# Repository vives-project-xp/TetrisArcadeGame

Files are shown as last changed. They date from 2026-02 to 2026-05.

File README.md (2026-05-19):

# TETRIS ARCADE GAME






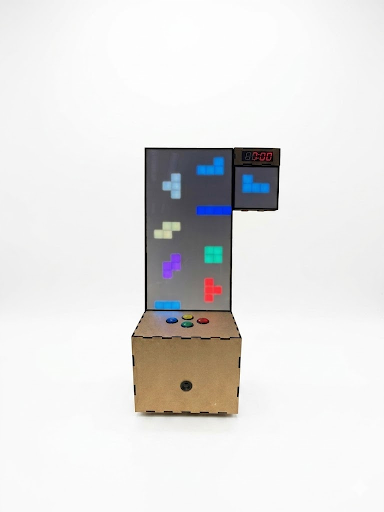
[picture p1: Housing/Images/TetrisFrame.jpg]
Tetris Frame


## Table of Contents
- [Team](#team)
- [Project Overview](#project-overview)
- [Features](#features)
- [Documentation](#documentation)
- [Posters](#posters)
- [Project Structure](#project-structure)

## Team
- [Danae Zutterman](https://github.com/Danaezutterman)
- [Lars Ysebaert](https://github.com/LarsYse)
- [Finn Van Peteghem](https://github.com/finn6698)
- [Timo Plets](https://github.com/TimoPlts)
- [Ondřej Kozel](https://github.com/ondrejkozel)

## Project Overview
This project focuses on the design and realization of a physical Tetris arcade game inside a custom-built housing. The game is displayed in real time on an LED game board and includes a scoreboard and a next-block display. A Raspberry Pi acts as the main controller, handling the physical button inputs while driving the LED matrix and speaker output.

The system is designed as a complete arcade experience rather than only a software project. In addition to the game logic, this repository also contains documentation for the hardware, housing, posters, and Raspberry Pi autostart setup.

## Documentation
- [Documentation overview](./Documentation/README.md) for the full documentation index
- [Architecture](./Documentation/Architecture/README.md) for the electrical and LED diagrams
- [Autostart](./Documentation/Autostart/Autostartscript.md) for the Raspberry Pi `systemd` service setup
- [Housing](./Housing/README.md) for the housing and laser-cutting related files

## Posters
<div style="display: flex; gap: 10px;">
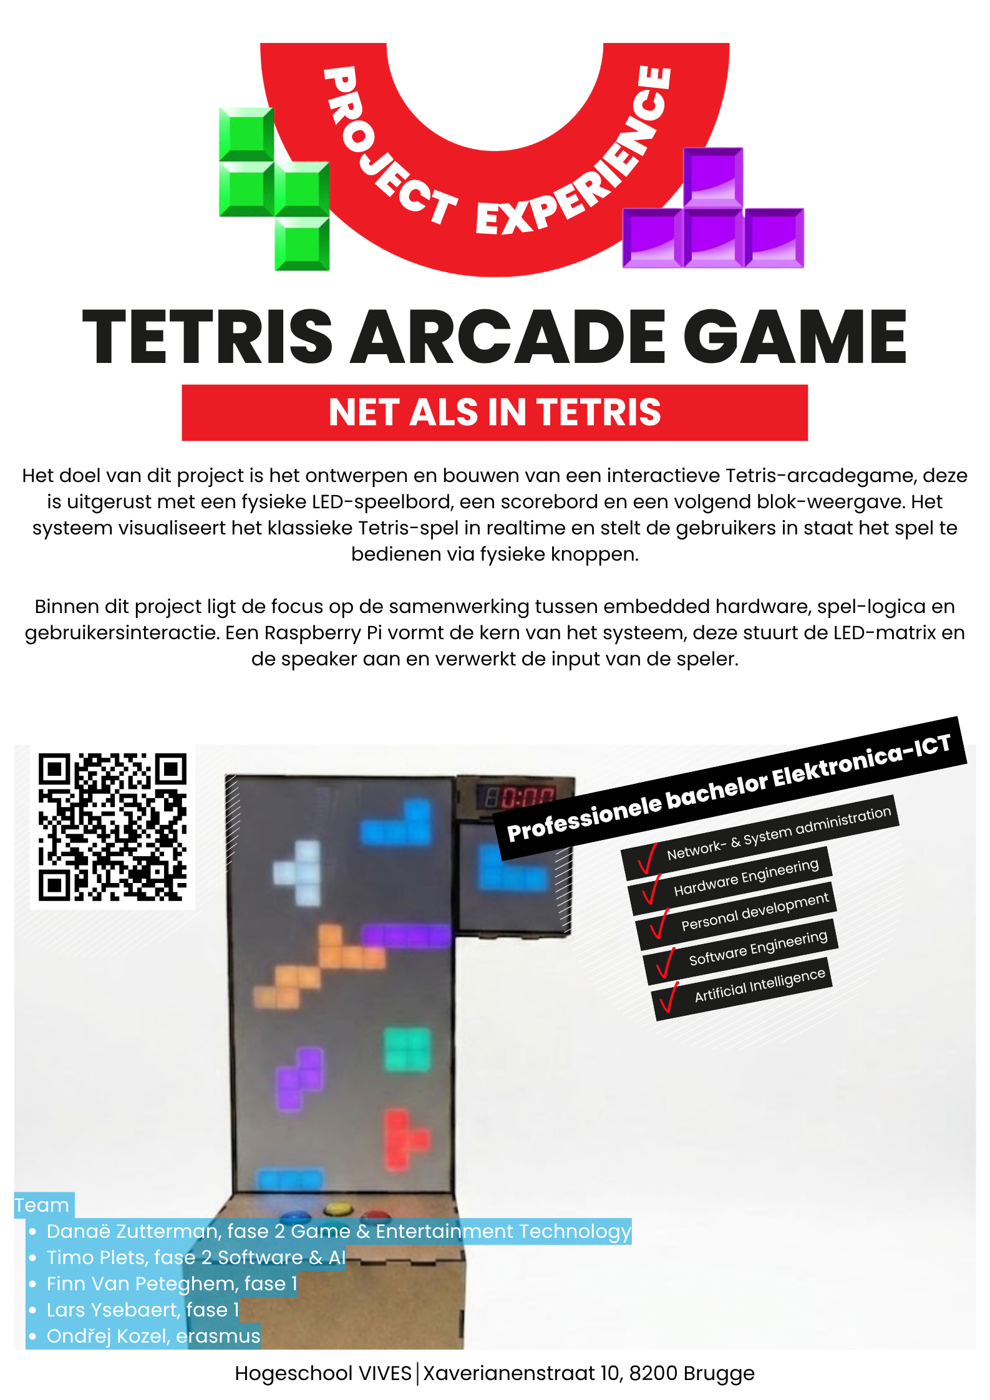
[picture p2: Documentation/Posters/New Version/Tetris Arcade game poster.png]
Tetris Arcade poster
   
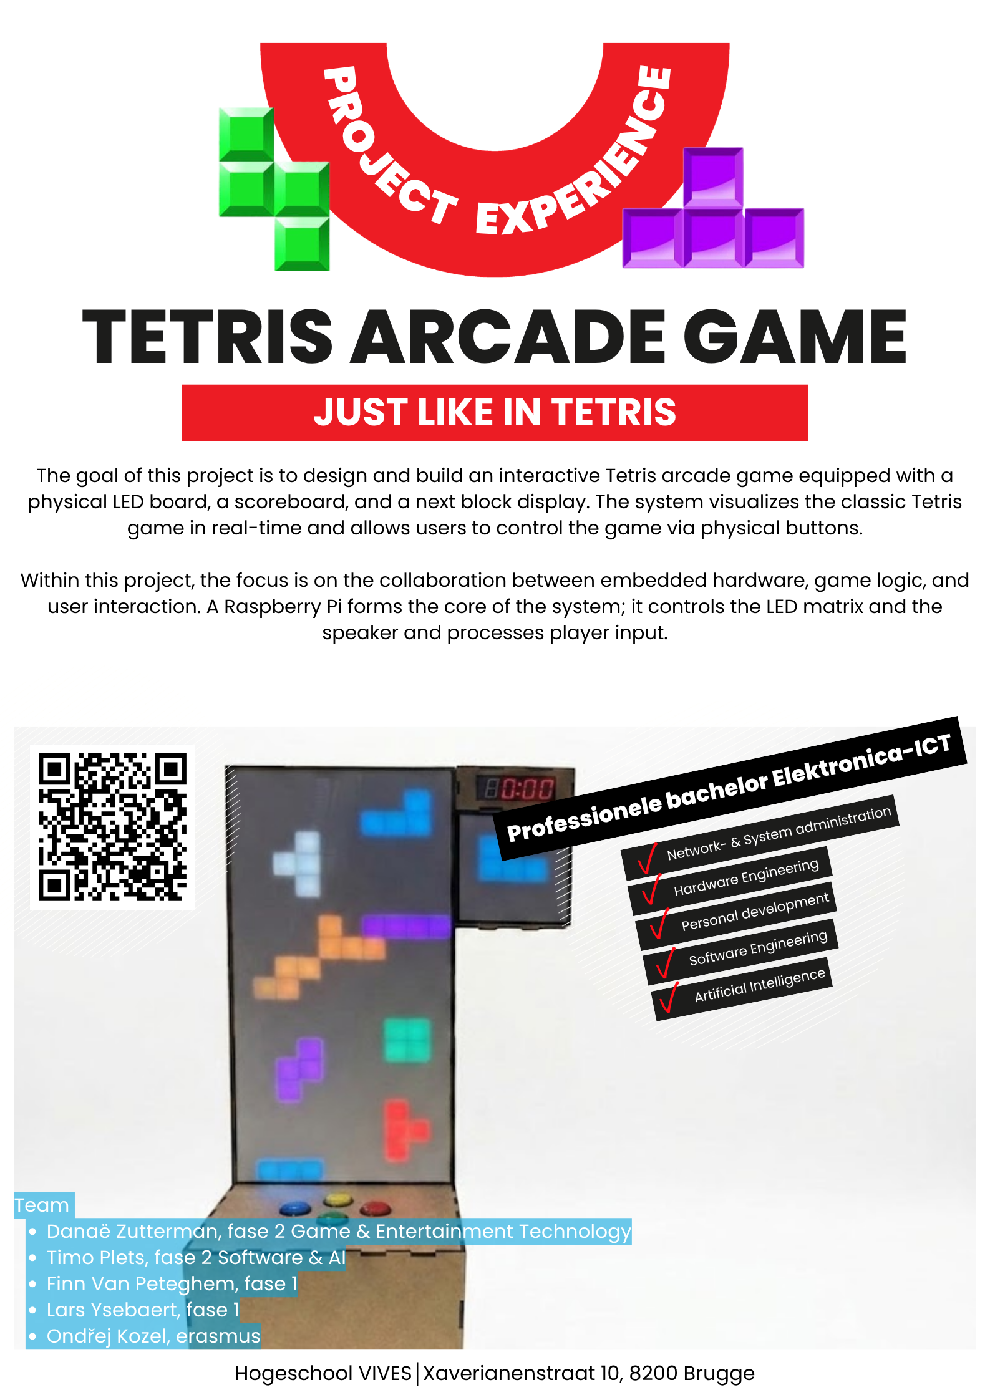
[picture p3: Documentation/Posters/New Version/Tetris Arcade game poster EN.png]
Tetris Arcade poster in English
   
</div>

## Project Structure
- [Documentation](./Documentation/README.md): project documentation, architecture, autostart, bill of materials, and posters
- [Housing](./Housing/README.md): housing design and related fabrication files
- [Social Media](./Social%20Media): images and videos created for communication and promotion
- [src](./src): source code for the game and LED-related software

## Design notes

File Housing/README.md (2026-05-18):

# Housing

Here you can find everything to make the housing step-by-step for laser cutting and assemble everything.

## Step 1

To visualize our **idea**, we first created a 3D model in Fusion.
This allowed us to check if the design looked good and if the layout worked well. 
By doing this first, we were then able to start drawing each individual part separately in Fusion.

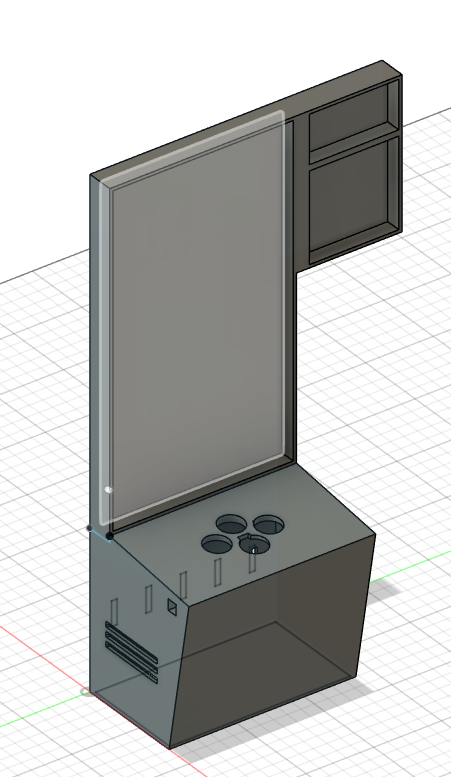
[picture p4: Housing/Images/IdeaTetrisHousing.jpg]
 

## Step 2

Next, we designed the **playfield** separately in Fusion. We added small rectangles at the ends so that all the parts fit together perfectly. We also included grooves on all sides to make sure the inner plates slide right in. On the back of these inner plates, we made small channels so the LED strip can easily be attached to the backplate.

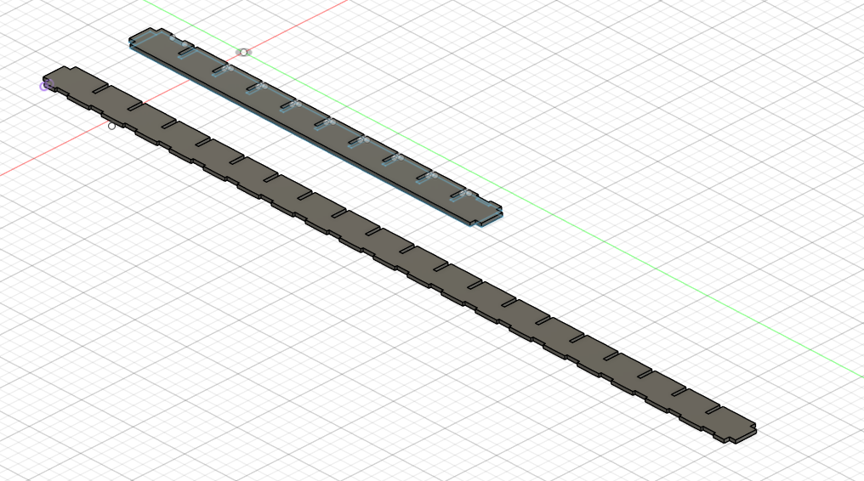
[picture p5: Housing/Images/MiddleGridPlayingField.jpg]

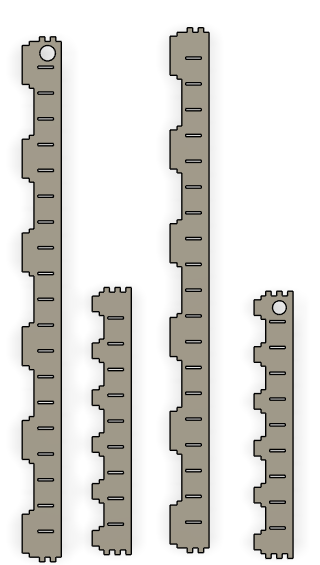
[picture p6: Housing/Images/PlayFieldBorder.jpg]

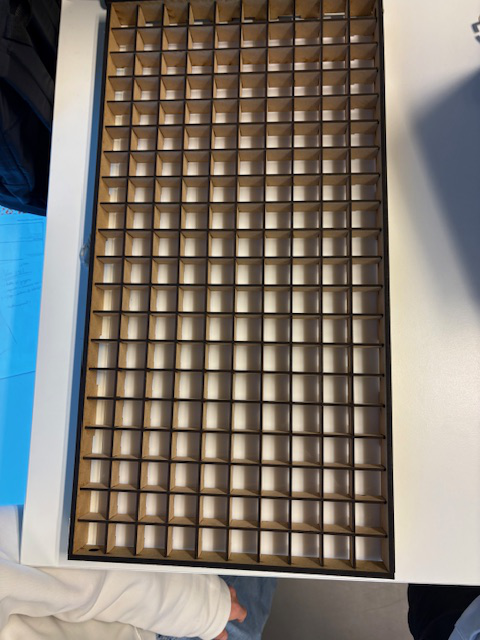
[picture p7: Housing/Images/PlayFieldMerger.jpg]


## Step 3

Then, we designed the **next field block** separately in Fusion, using the same method as we did for the playfield.

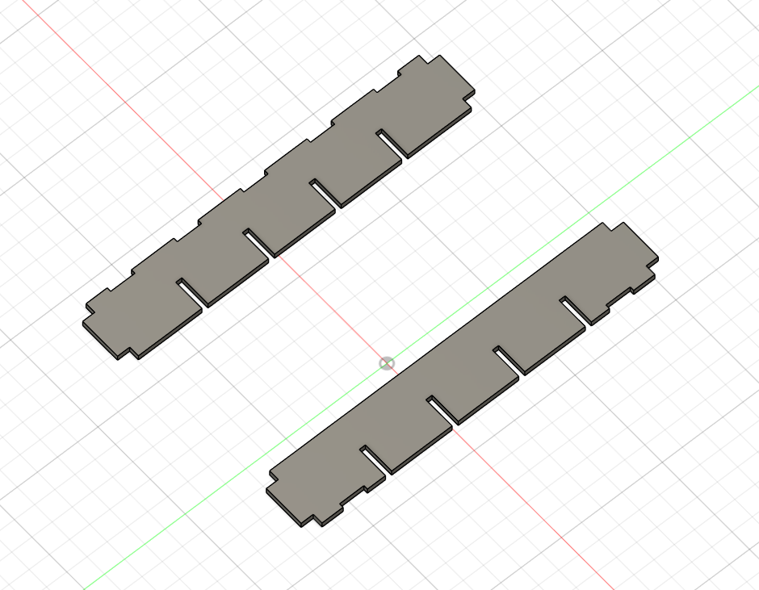
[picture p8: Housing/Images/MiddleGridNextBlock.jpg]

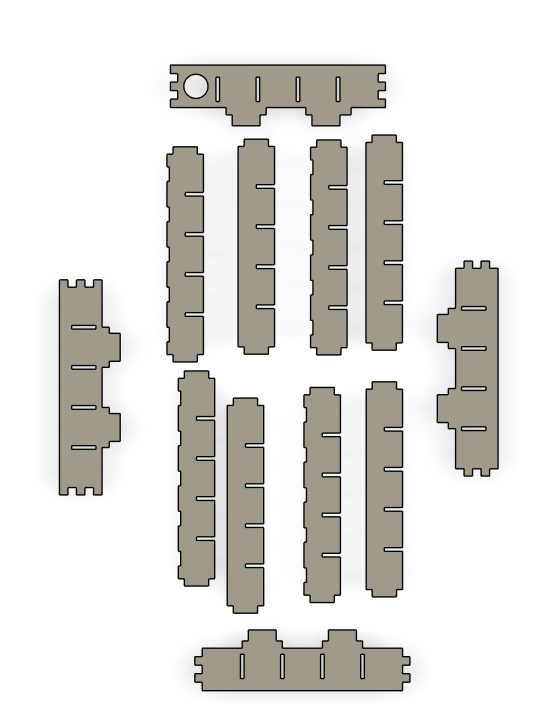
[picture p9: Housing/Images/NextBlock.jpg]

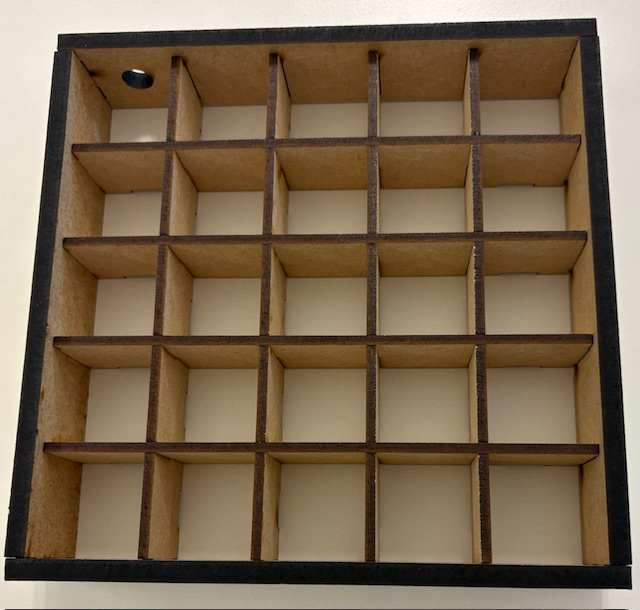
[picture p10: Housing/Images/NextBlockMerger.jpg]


## Step 4

Behind that, we designed the **console and the 2 backplates** separately in Fusion. We added small rectangles at the edges so they fit together perfectly. On both sides of the console, we created slots for ventilation. We also included a hole at the front for the speaker. On top of the console, we made five holes: four for the game buttons and one for the play/pause button. Finally, we placed an on/off switch on the left side.

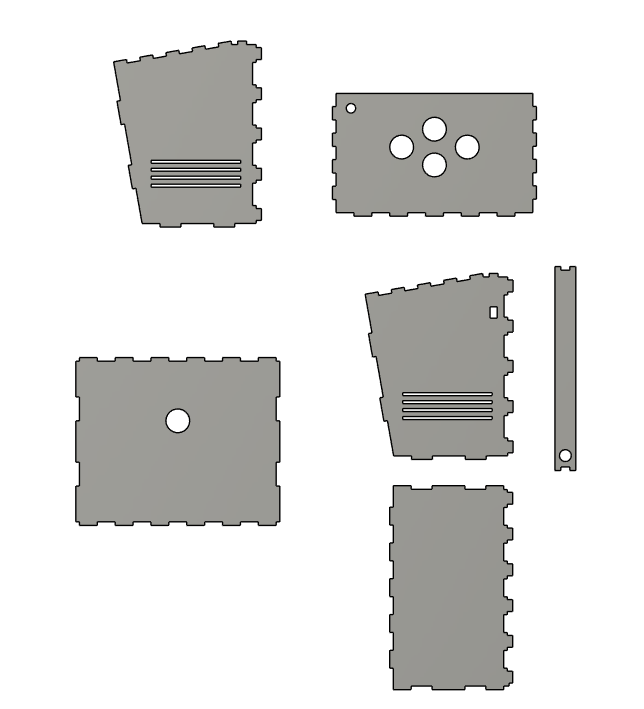
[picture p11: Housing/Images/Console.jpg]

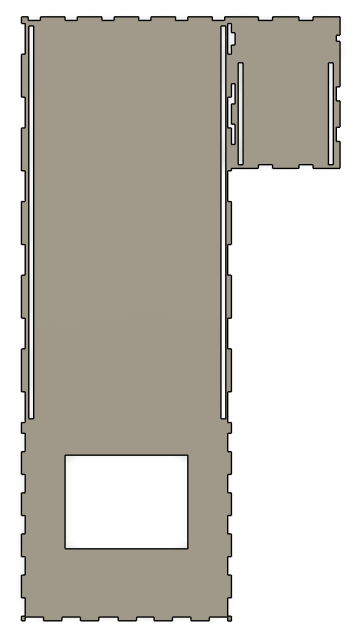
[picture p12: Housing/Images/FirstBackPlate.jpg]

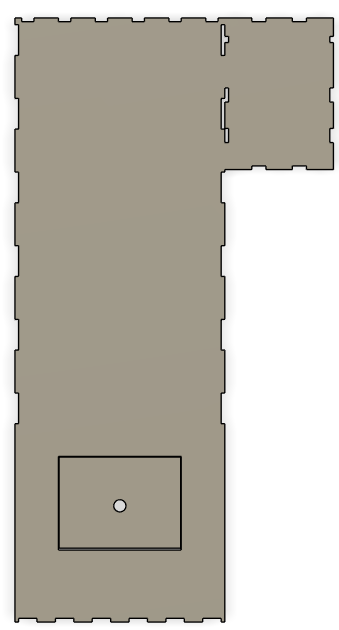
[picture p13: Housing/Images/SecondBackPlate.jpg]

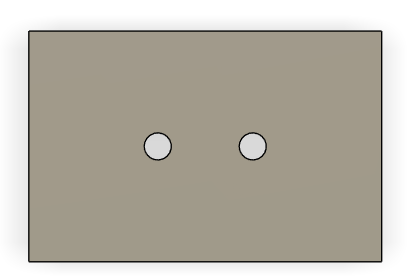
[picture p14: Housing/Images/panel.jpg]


## Step 5

Finally, we put everything together.



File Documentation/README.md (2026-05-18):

# Documentation

This folder contains the main project documentation for the Tetris Arcade Game. It brings together the hardware diagrams, Raspberry Pi startup configuration, bill of materials, and project posters.

## Contents
- [Architecture](./Architecture/README.md): electrical diagram, LED diagram, and UML-related documentation
- [Autostart](./Autostart/Autostartscript.md): Raspberry Pi autostart setup and the `tetris.service` configuration
- [BOM-list](./BOM-list/README.md): bill of materials with the parts needed for the project
- [Posters](./Posters): project posters and presentation material

Use this folder as the starting point for the non-code documentation of the project.

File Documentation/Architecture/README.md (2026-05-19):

# Architecture

This folder contains the diagrams that explain both the hardware wiring and the system structure of the Tetris arcade.

## Hardware Diagrams

The electrical diagram and the LED diagram belong together. The electrical diagram shows how the electronics are connected, while the LED diagram explains how the LED matrix is arranged so the software can map the in-game grid to the physical display.

<div style="display: flex; flex-wrap: wrap; gap: 16px; align-items: flex-start;">
   <div>
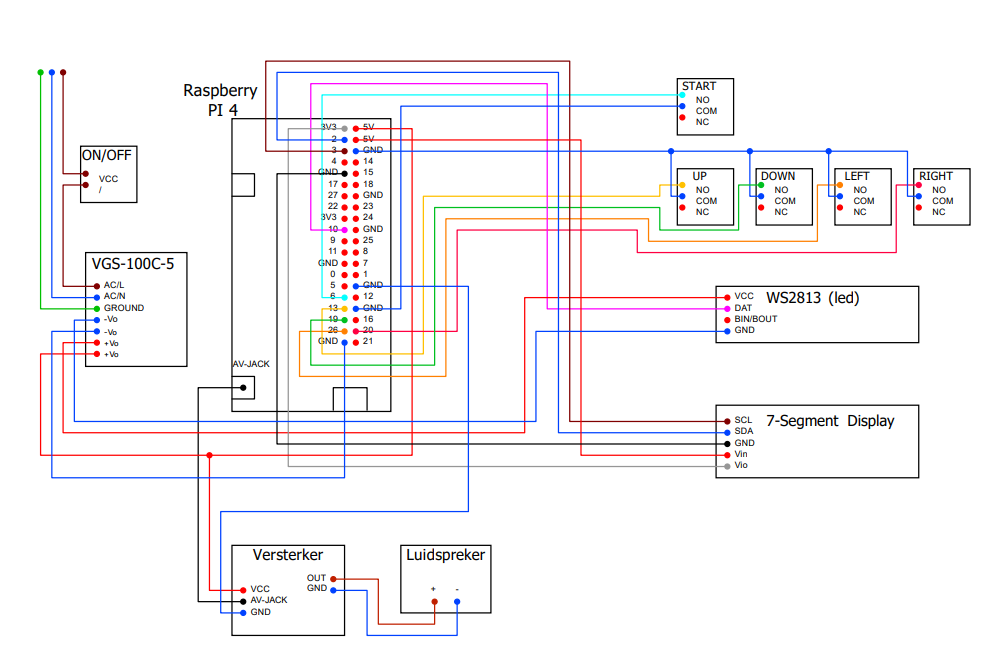
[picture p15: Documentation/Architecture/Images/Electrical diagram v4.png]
Electrical diagram of the Tetris arcade game
      
      <p><strong>Electrical diagram</strong><br>Overview of the power, signal, and controller connections inside the arcade system.</p>
   </div>
   <div>
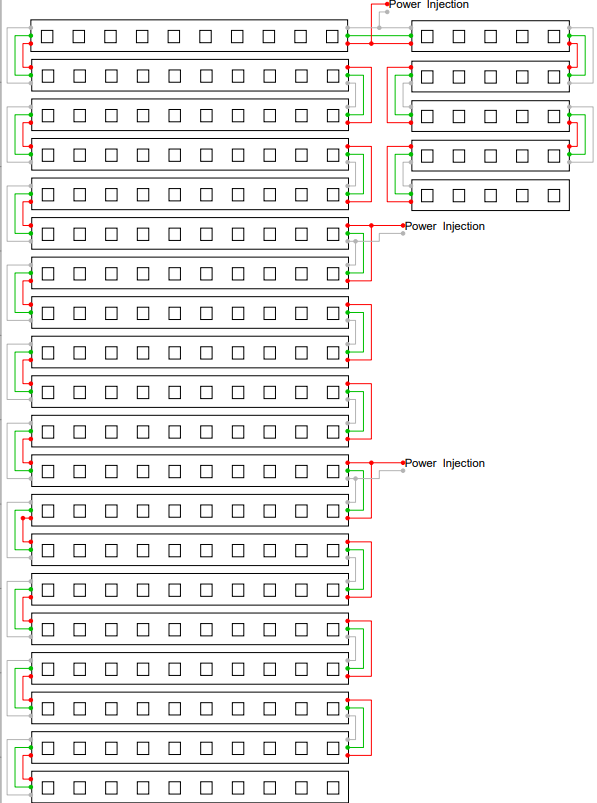
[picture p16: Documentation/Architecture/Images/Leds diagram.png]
LED diagram of the Tetris arcade game
      
      <p><strong>LED diagram</strong><br>This diagram shows the LED layout and helps relate the physical LED positions to the game logic and animations.</p>
   </div>
</div>

## UML Diagrams

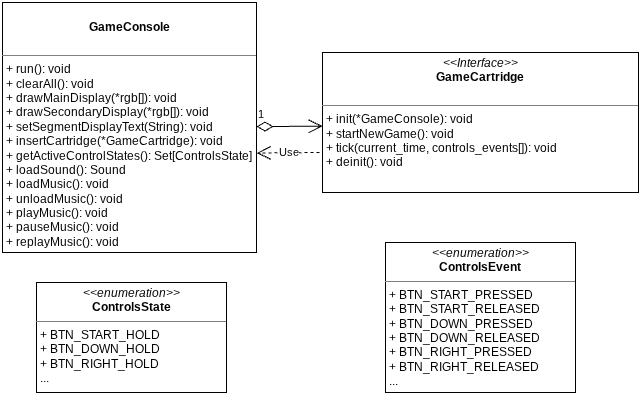
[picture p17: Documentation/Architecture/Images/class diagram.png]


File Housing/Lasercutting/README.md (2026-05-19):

# Lasercutting

This folder contains all the parts needed for laser cutting the different sections.

## Parts

- [Back Plate](./Backplate) : Here you can find the file for laser cutting the backplate.
- [Console](./Console) : Here you can find the file for laser cutting the console.
- [Grid](./Grid) : Here you can find the filse for laser cutting the Playing Field & Next Block Field.

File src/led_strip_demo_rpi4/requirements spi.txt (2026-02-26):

Adafruit-Blinka==8.69.0
adafruit-circuitpython-busdevice==5.2.15
adafruit-circuitpython-connectionmanager==3.1.6
adafruit-circuitpython-lis3dh==5.2.8
adafruit-circuitpython-neopixel==6.3.21
adafruit-circuitpython-neopixel-spi==1.0.14
adafruit-circuitpython-pixelbuf==2.0.10
adafruit-circuitpython-requests==4.1.15
adafruit-circuitpython-typing==1.12.3
Adafruit-PlatformDetect==3.88.0
Adafruit-PureIO==1.1.11
binho-host-adapter==0.1.6
pyftdi==0.57.1
pyserial==3.5
pyusb==1.3.1
RPi.GPIO==0.7.1
sysv_ipc==1.2.0
typing_extensions==4.15.0

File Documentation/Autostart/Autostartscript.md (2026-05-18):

# Raspberry Pi Autostart Setup

This document explains how the Tetris Arcade game starts automatically when the Raspberry Pi receives power and finishes booting. The setup uses a `systemd` service that launches the Python application in `src/game_console`.

## Overview

The service file used for this project is stored in [tetris.service](./tetris.service). It starts the game from the following location:

- Project folder: `/home/tetris02/TetrisArcadeGame`
- Game folder: `/home/tetris02/TetrisArcadeGame/src/game_console`
- Python executable: `/home/tetris02/TetrisArcadeGame/src/game_console/venv/bin/python`
- Main file: `/home/tetris02/TetrisArcadeGame/src/game_console/main.py`

## 1. Copy the project to the Raspberry Pi

Make sure the repository is present on the Raspberry Pi at:

```bash
/home/tetris02/TetrisArcadeGame
```

If your project is stored in another location or under another user, you must update the paths in the service file.

## 2. Make sure the virtual environment exists

The service starts the game with the Python interpreter inside the virtual environment. Verify that this interpreter exists:

```bash
ls /home/tetris02/TetrisArcadeGame/src/game_console/venv/bin/python
```

If needed, create the virtual environment and install the required packages:

```bash
cd /home/tetris02/TetrisArcadeGame/src/game_console
python3 -m venv venv
source venv/bin/activate
pip install -r requirements.txt
```

## 3. Create the `systemd` service

Create a service file, for example:

```bash
sudo nano /etc/systemd/system/tetris.service
```

Add the following configuration. This is the same service definition as in [tetris.service](./tetris.service):

```ini
[Unit]
Description=Tetris Arcade Game
After=multi-user.target

[Service]
Type=simple
User=root
WorkingDirectory=/home/tetris02/TetrisArcadeGame/src/game_console
ExecStart=/home/tetris02/TetrisArcadeGame/src/game_console/venv/bin/python /home/tetris02/TetrisArcadeGame/src/game_console/main.py
Restart=always
RestartSec=5

[Install]
WantedBy=multi-user.target
```

## 4. Reload `systemd`

After creating or changing the service file, reload the `systemd` configuration:

```bash
sudo systemctl daemon-reload
```

## 5. Enable the service

Enable the service so it starts automatically after every boot:

```bash
sudo systemctl enable tetris.service
```

## 6. Start the service

Start it manually once to verify the configuration:

```bash
sudo systemctl start tetris.service
```

## 7. Check the service status

Use the following command to confirm that the service is running:

```bash
sudo systemctl status tetris.service
```

If everything is configured correctly, you should see a result similar to:

```text
* tetris.service - Tetris Arcade Game
     Loaded: loaded (/etc/systemd/system/tetris.service; enabled)
     Active: active (running)
     Main PID: 1234 (python)
```

Important things to verify:

- `Loaded: enabled` means the service will start automatically on boot.
- `Active: active (running)` means the game is currently running.
- `Main PID` confirms that the Python process was started by `systemd`.

## 8. Check the logs

If the service does not start correctly, inspect the logs:

```bash
sudo journalctl -u tetris.service -e
```

To follow the logs live:

```bash
sudo journalctl -u tetris.service -f
```

## 9. Test the autostart behavior

Reboot the Raspberry Pi:

```bash
sudo reboot
```

After the Raspberry Pi has started again, check the service once more:

```bash
sudo systemctl status tetris.service
```

If the autostart works correctly, the service should again show:

```text
Active: active (running)
```

This confirms that the Tetris Arcade game starts automatically when the Raspberry Pi powers on.

## Notes

- The current service file uses `User=root`. If you want to run the game as another user, update `User`, `WorkingDirectory`, and `ExecStart` together.
- If the repository path changes, the service file must be updated to match the new location.
- The service definition itself is stored in [tetris.service](./tetris.service) for reference.

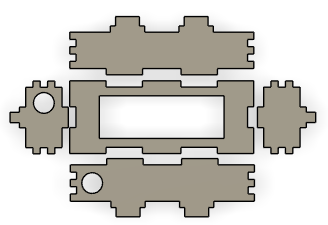
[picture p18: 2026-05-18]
Housing/Images/ScoreDisplay.jpg

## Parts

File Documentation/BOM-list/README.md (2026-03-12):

## Bill of Materials (BOM) - Tetris Arcade Game

| Aantal | Component | Leverancier | Type / ID | Prijs (p.st.) | Link |
| :--- | :--- | :--- | :--- | :--- | :--- |
| 2 | **RGBW LEDS** (150 leds, 5m) | Tinytronics | WS2813 | € 30,25 | [Link](https://www.tinytronics.nl/en/lighting/led-strips/led-strips/worldsemi-ws2813-digital-5050-rgbw-led-strip-30-leds-5m) |
| 1 | **Large Red Push Button** | Tinytronics | 828 | € 3,50 | [Link](https://www.tinytronics.nl/en/switches/manual-switches/push-buttons-and-switches/large-red-push-button-24mm-of-40mm-reset) |
| 1 | **Large Green Push Button** | Tinytronics | 827 | € 3,50 | [Link](https://www.tinytronics.nl/en/switches/manual-switches/push-buttons-and-switches/large-green-push-button-24mm-of-40mm-reset) |
| 1 | **Large Blue Push Button** | Tinytronics | 826 | € 3,50 | [Link](https://www.tinytronics.nl/en/switches/manual-switches/push-buttons-and-switches/large-blue-push-button-24mm-of-40mm-reset) |
| 1 | **Large Yellow Push Button** | Tinytronics | 830 | € 3,50 | [Link](https://www.tinytronics.nl/en/switches/manual-switches/push-buttons-and-switches/large-yellow-push-button-24mm-of-40mm-reset) |
| 1 | **AC/DC PSU** (5V, 90W, 18A) | Farnell | VGS-100C-5 | € 17,21 | [Link](https://be.farnell.com/cui/vgs-100c-5/power-supply-ac-dc-5v-18a/dp/3594891) |
| 1 | **Stereo Audio Amp** (5V) | Tinytronics | PAM8406 | € 5,00 | [Link](https://www.tinytronics.nl/en/audio/amplifiers/2x3w-stereo-audio-amplifier-mini-5v-pam8406-volume-control-with-screw-terminals) |
| 1 | **Speaker** (5W, 4 Ohm) | Otronic | OT40-B33 | € 4,90 | [Link](https://www.otronic.nl/nl/speakertje-3w-40mm.html) |
| 1 | **Rocker Switch** | Tinytronics | 210 | € 0,50 | [Link](https://www.tinytronics.nl/en/switches/manual-switches/rocker-switches/standaard-built-in-rocker-switch-normal) |
| 1 | **Black Push Button** | Tinytronics | 795 | € 2,50 | [Link](https://www.tinytronics.nl/en/switches/manual-switches/push-buttons-and-switches/black-push-button-16mm-reset) |
| 1 | **Vynex Meubelscharnier** | Brico | 5473366 | € 4,99 | [Link](https://www.brico.be/nl/ijzerwaren/meubelbeslag/meubelscharnieren/kogelscharnieren/vynex-meubelscharnier-verzinkt-staal-30x19-mm-4-stuks/5473366) |
| 1 | **7-segment Display 4-Digit** | Kiwi Electronics | ADA-1270 | € 19,11 | [Link](https://www.kiwi-electronics.com/nl/3cm-4-digit-7-segment-display-met-i2c-backpack-rood-418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) |
| --- | --- | --- | --- | --- | --- |
| **Total** | | | | | **€ 128.71** |

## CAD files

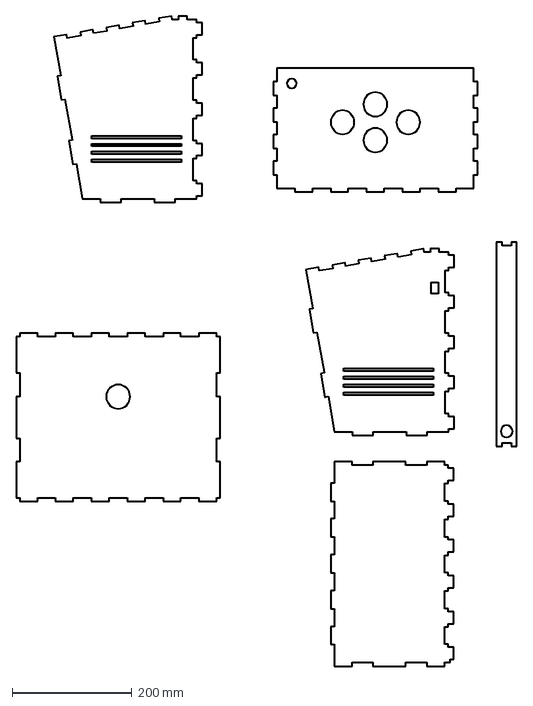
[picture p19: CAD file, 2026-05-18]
Housing/Lasercutting/Console/FINAL_CONSOLE.dxf
838.4 x 1087.7 mm

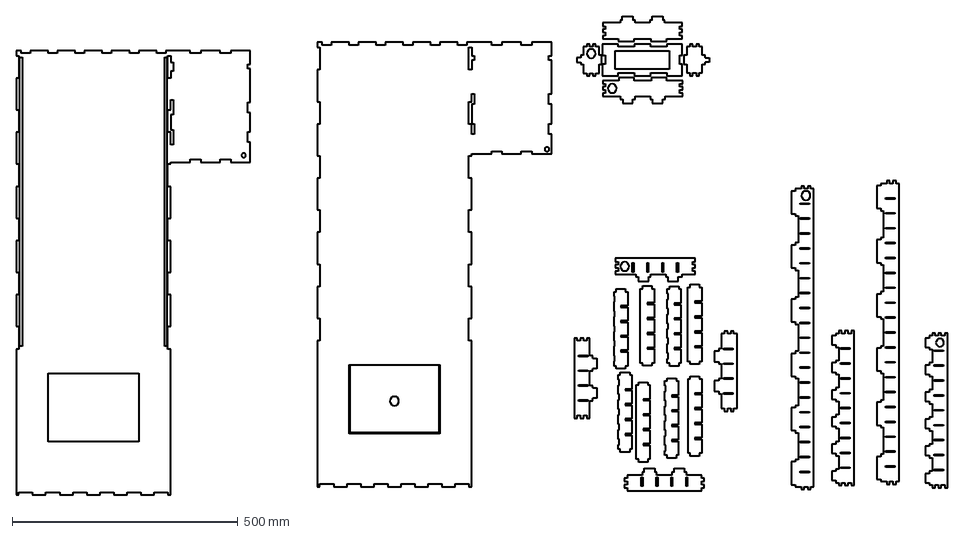
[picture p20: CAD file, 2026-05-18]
Housing/Lasercutting/Backplate/Double_BackplateV1 Sheet1.dxf
2063.7 x 1060.5 mm

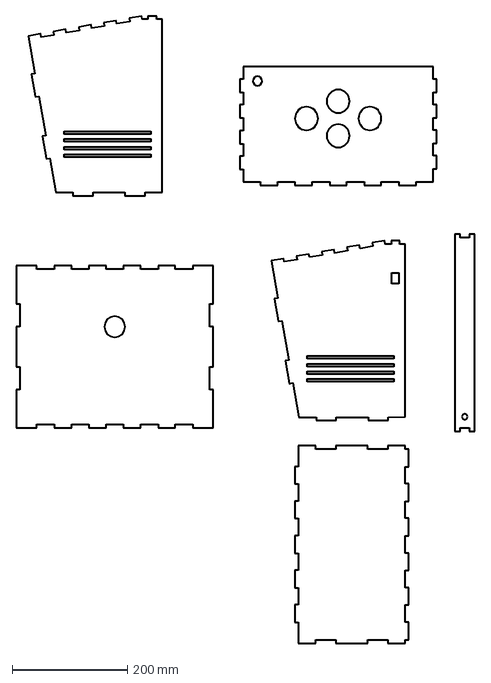
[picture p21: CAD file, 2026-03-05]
Housing/Lasercutting/Console/TETRIS_Console_V10.dxf
795.5 x 1087.7 mm

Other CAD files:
Housing/Lasercutting/Backplate/FINAL_BACKPLATE_GRID.dxf
Housing/Lasercutting/Grid/FINAL_BACKPLATE_GRID.dxf
Housing/Lasercutting/Grid/middenrooster_tetris_grootV10.dxf
Housing/Lasercutting/Backplate/FINAL_BACKPLATE_GRID.f3d
Housing/Lasercutting/Console/FINAL_CONSOLE.f3d
Housing/Lasercutting/Grid/FINAL_BACKPLATE_GRID.f3d

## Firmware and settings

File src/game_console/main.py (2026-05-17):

from cartridges.test_cartridge import TestCartridge
from cartridges.tetris_cartridge import TetrisCartridge
from cartridges.snake_cartridge import SnakeCartridge
from cartridges.pong_cartridge import PongCartridge
from console.game_console import GameConsole


def main() -> None:
    """Main entry point for the game console."""
    console = GameConsole()
    console.set_available_cartridges([TetrisCartridge, SnakeCartridge, PongCartridge])
    console.insert_cartridge(TetrisCartridge())
    console.run()


if __name__ == "__main__":
    main()

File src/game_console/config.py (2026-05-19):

from console.controls import ControlsState
import board

# Game loop settings
TARGET_FPS = 30
FRAME_TIME = 1.0 / TARGET_FPS
SCREENSAVER_TIMEOUT_S = 20.0

# LED Display settings
MAIN_MATRIX_WIDTH = 10
MAIN_MATRIX_HEIGHT = 20
SECONDARY_MATRIX_WIDTH = 5
SECONDARY_MATRIX_HEIGHT = 5
LED_STRIP_PIN = board.D10
LED_BRIGHTNESS = 1.0 # 0.0 to 1.0

MAIN_MATRIX_PIX_COUNT = MAIN_MATRIX_WIDTH * MAIN_MATRIX_HEIGHT
SECONDARY_MATRIX_PIX_COUNT = SECONDARY_MATRIX_WIDTH * SECONDARY_MATRIX_HEIGHT
MAIN_MATRIX_OFFSET = 0
SECONDARY_MATRIX_OFFSET = MAIN_MATRIX_PIX_COUNT
LED_STRIP_LEN = MAIN_MATRIX_PIX_COUNT + SECONDARY_MATRIX_PIX_COUNT

# Seven segment display settings
SEVEN_SEGMENT_I2C_ADDRESS = 0x70
SEVEN_SEGMENT_LED_BRIGHTNESS = 15 # 0 to 15 inclusive
SEVEN_SEGMENT_DIGITS = 4

# GPIO pin mappings for physical buttons (BCM)
BUTTON_GPIO_MAPPING = {
    6: ControlsState.BTN_START_HOLD,
    13: ControlsState.BTN_UP_HOLD,
    19: ControlsState.BTN_DOWN_HOLD,
    26: ControlsState.BTN_LEFT_HOLD,
    20: ControlsState.BTN_RIGHT_HOLD,
}

# Audio settings
AUDIO_ASSETS_PATH = "assets/sounds/"
AUDIO_SAMPLE_RATE = 22050
AUDIO_BUFFER_SIZE = 512

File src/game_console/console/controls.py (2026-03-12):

from enum import Enum, auto


class ControlsState(Enum):
    """The state of controls (held buttons)."""
    BTN_START_HOLD = auto()
    BTN_UP_HOLD = auto()
    BTN_RIGHT_HOLD = auto()
    BTN_DOWN_HOLD = auto()
    BTN_LEFT_HOLD = auto()


class ControlsEvent(Enum):
    """Control events (button press/release)."""
    BTN_START_PRESSED = auto()
    BTN_START_RELEASED = auto()
    BTN_UP_PRESSED = auto()
    BTN_UP_RELEASED = auto()
    BTN_RIGHT_PRESSED = auto()
    BTN_RIGHT_RELEASED = auto()
    BTN_DOWN_PRESSED = auto()
    BTN_DOWN_RELEASED = auto()
    BTN_LEFT_PRESSED = auto()
    BTN_LEFT_RELEASED = auto()

def control_state_to_event(state: ControlsState, pressed: bool) -> ControlsEvent:
    """
    Converts a control state to a control event.
    
    Args:
        state: The control state
        pressed: True for pressed event, False for released event
        
    Returns:
        The corresponding ControlsEvent
    """
    suffix = "PRESSED" if pressed else "RELEASED"
    event_name = state.name.replace("_HOLD", f"_{suffix}")
    return ControlsEvent[event_name]

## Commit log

2026-03-05 Add BOM for Tetris Arcade Game
2026-03-05 Add total cost to BOM list in README
2026-03-05 Lasercutting files
    [Backplate_V11.dxf, TETRIS_Console_V10.dxf, middenrooster next block drawing.dxf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]
2026-03-05 3d-prints files
    [Bracket 20.stl, Bracket 40.stl, Corner_double.gcode.3mf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]
2026-03-05 images housing
2026-03-12 feat: button reading
2026-03-12 code led strip
2026-03-12 feat: led strip impr
2026-03-12 led strip
2026-03-12 update readme 3d-prints
2026-03-19 fill method led strip
2026-03-19 chore: led strip refactor
2026-03-19 afbeeldingen 3d-prints
2026-03-19 fix: debug prints
2026-03-26 fix: mirror the led
    [game_console.py]
2026-03-26 Update Readme with picture
    Translated the README content from Dutch to English and added images for better visualization of the housing design process.
2026-03-31 Pictures from housing
2026-04-02 feat: tetris fast down, set led brightness
2026-04-16 First version of the new double backplate
    needs to be recalculated and needs holes in the next block backplate
    [Double_BackplateV1 Sheet1.dxf]
2026-04-23 feat: render current score
2026-04-23 fix: next piece display mirroring
    [game_console.py]
2026-04-23 feat: start button impl
2026-04-30 game start fix & tetris terminal sim
    [simulate_tetris_terminal.py]
2026-05-14 Change the names in the 3D prints folder to English.
    [Bracket 20.stl, Bracket 40.stl, Corner_double.gcode.3mf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]
2026-05-18 changing the folder map from 3D prints & Lasercutting
    [Backplate_V11.dxf, Bracket 20.stl, Bracket 40.stl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]
2026-05-18 deleting the folder 3D prints
    [Bracket 20.stl, Bracket 40.stl, Corner_double.gcode.3mf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]
2026-05-18 New Pictures of the housing
    [middenrooster next block drawing.dxf, middenrooster_tetris_grootV10.dxf, omranding next block drawing.dxf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]
2026-05-18 Changing the pictures in the step plan
    Updated images and descriptions for clarity in housing assembly steps.
2026-05-18 Picture from the frame
2026-05-18 Console lasercut file
    [FINAL_CONSOLE.dxf, FINAL_CONSOLE.f3d]
2026-05-18 lasercut file grid + backplate
    [Backplate_V11.dxf, FINAL_BACKPLATE_GRID.dxf, FINAL_BACKPLATE_GRID.f3d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]
2026-05-19 Picture in the README and fixing the readme in lasercutting with the folder structure
